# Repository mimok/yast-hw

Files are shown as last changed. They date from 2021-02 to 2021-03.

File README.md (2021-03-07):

# Yet Another Security Token v1.0
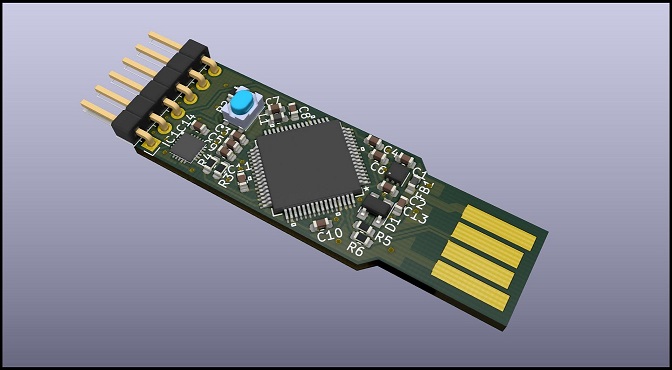
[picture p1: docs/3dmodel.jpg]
YAST token illustration v1.0


## Purpose of this token
This repository contains the hardware source files of the YAST security token.
This security token is intented to be used as a development platform for security applications.
It is built around a LPC55Sxx chip and a SE050 secure element both from NXP.
This token as the same form factor as the [OpenSK](https://github.com/google/OpenSK) token
from Google therefore its [case](https://www.thingiverse.com/thing:4132768) can be reused.

## Disclaimer
YAST is designed to be a development board and therefore should not be used as a daily security token.

## What is the added value of YAST?
On the market there is already a large amount of security tokens.
Most of them are based on proprietary designs while some others are open source.
On one hand, closed source tokens seem to be based on secure elements while on the other hand, as far as I know, open source tokens
are based on standard, not security certified, chips like STM32 chips.
This design choice seems to be mainly dictated by concerns about NDA which come with Secure Elements.

From my point of view this is a real problem. I agree some tokens based on secure elements are not exempt from vulnerabilities like the 
[Titan security key](https://www.zdnet.com/article/new-side-channel-attack-can-recover-encryption-keys-from-google-titan-security-keys/) from Google.
In fact, this token is based on a pretty old secure element A7005 from NXP and therefore things which were secure almost ten years ago are no more secure now.
However if a old secure element is now vulnerable (but more than 4 months of work were needed to discover and exploit the vulnerability), 
old non secure chips are **far more** vulnerable. For example, it is possible to [extract the firmware](https://blog.zapb.de/stm32f1-exceptional-failure/) 
from an STM32F1 chip using a pure software attack (ok this is not entirely true as an access to the SWD port is needed). 
This is this chip which is used in the Nitrokey Start key from Nitrokey. While using a secure element is not a "cure-all", 
using non-secure and non-certified chips for secure application is almost always a bad idea as you relies on a "untrusted" 
(not certified) chip exectuting an "untrusted" (not certified) code. 
Here openness is not really a huge advantage as there is very few people around the world which have the required 
skills needed to perform a valuable security assessment of a security token.

So how a security token can be built using a secure element and still be open source? 
[SE050 security chip](https://www.nxp.com/products/security-and-authentication/authentication/edgelock-se050-plug-trust-secure-element-family-enhanced-iot-security-with-maximum-flexibilit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) 
from NXP is a pre-programmed secure element embedding a really versatile security applet. 
All documentation is freely accessible on NXP's website (some documentation requires an account to be accessible) and therefore no NDA is required. 
The YAST key embeds both a LPC55Sxx chip and the SE050 SE. LPC55Sxx chip can be binded to its SE050 companion using its embedded PUF (Physical Unclonable Function). 
The resulting hardware comes with both the flexibility and the power of the LPC55 chip and the security of the SE050 secure element which has been certified at level EAL6+ (Hardware and OS) according to the Common Criterias.

## For which application the YAST token can be used?
YAST token is made of a LPC55Sxx MCU connected to a SE050 coprocessor which acts as a secure cryptographic library.
SE050 is designed to prevent both leakage of cryptographic keys and their usage by unauthorized users. In consequence, YAST token is suited for
applications which extensively use cryptographic primitives. However, others processing taking place on the LPC55 side do not benefit from SE050 high
security level. So before using YAST token for a given application, you should be sure that the following hypothesis are verified:
- LPC55Sxx does not implements any security functions and it is only used as an interface between SE050 chip and the host PC.
- Or, LPC55Sxx implements some security function but they can only be used if the user is properly authenticated by the SE050 **and** , 
if we consider the application threat model,the user is not willing to attack his own token.

Concretely, the YAST token can be used to implement application like OpenPGP card (demo application available), 
FIDO2 protocol (but YAST token does not have any led) or HSM-like applications.

SE050 has some functional limitations which can be circumvented:

- PIN object cannot be atomically updated. You have to first delete then create a new PIN object. 
If a power loss occurs between PIN deletion and creation then the secure element remains in an improper state which can be exploited by an attacker. 
Therefore my advise is to lock the secure element using the new PIN before the deletion of the old PIN and unlock the SE at the end of the process. 
In case of power loss during PIN update, the SE is locked at next reboot and the improper state of the SE cannot be exploited by an attacker which does not have the knowledge of the new PIN.
- PIN try counters of PIN objects cannot be read (while there are effectively decremented when a wrong PIN is entered) 
so you will have to manage these counters by yourself. This limitation is corrected in the new version of the SE050 which is not yet available.

At the moment, due to a shortage in LPC55S69 chips, YAST token is based on a LPC55S28 chip which does not implement TrustZone.
However these two chips are PIN compatible and token design does not need to be changed if one wants to update the chip.

## Building the YAST token yourself
You can easily build this token yourself. The token is designed using Kicad v5 and you can inspect or modify its design.
You will need a PCB with a thickness of at least 2.0mm (best 2.4mm). You can also use a small piece of tape to improve the thickness of your PCB.
You should dispense paste on the PCB using a stencil. I use unleaded low temperature Chip Quik SMDLTLFP paste (melting point at 138°C).
Placement is not so hard because CMS are not smaller than 0603. The regulator, the SE050 and the LPC55 are the hardest parts to place.
Soldering is an easy game if you use a hot plate and a hot-air rework station.

## Programming and debugging
A 6-pin header is available for programming and debugging purpose through LPC55 SWD port. 
A low cost [LPC Link-2](https://www.nxp.com/design/microcontrollers-developer-resources/lpc-microcontroller-utilities/lpc-link2:OM13054)
from NXP can be used as a debugging probe. You should update it with the [segger firmware](https://www.segger.com/products/debug-probes/j-link/models/other-j-links/lpc-link-2/) to obtain the best performances.
USB port can also be used to program the LPC55 chip through the on-chip bootloader:

1. First you will have to enable the USB0 interface in the bootloader configuration. To do so, you can load and execute the following [piece of code](docs/unlock_USB0_bootloader.c) trough SWD interface.
2. Once bootloader has been unlocked, press the button on the token and plug it on your computer. Bootloader should be automatically detected on WIN10.
3. Then use [blhost](https://www.nxp.com/design/software/development-software/mcuxpresso-software-and-tools-/mcuboot-mcu-bootloader-for-nxp-microcontrollers:MCUBOOT) tool from NXP to flash your firmware:
    1. Compile your program using your preferred IDE (e.g. MCUXpresso) and generate an HEX file.
    2. Load the new HEX file using the following commands:

```bash
blhost -u 0x1FC9,0x21 -- flash-image <path_to_hex_file> erase 0
blhost -u 0x1FC9,0x21 -- reset
```

## Plastic case for YAST token
This token as the same form factor as the [OpenSK](https://github.com/google/OpenSK) token
from Google therefore its [case](https://www.thingiverse.com/thing:4132768) can be reused.
The case can be built using a 3D Printer and PLA plastic.

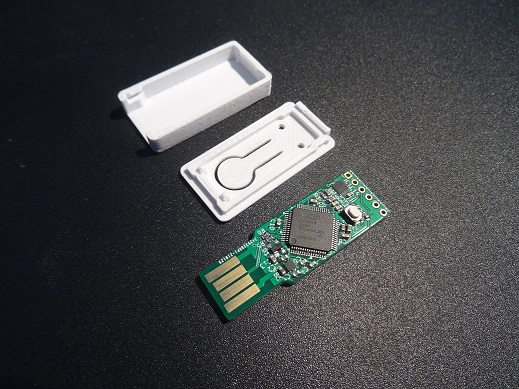
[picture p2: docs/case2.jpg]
Unmounted case


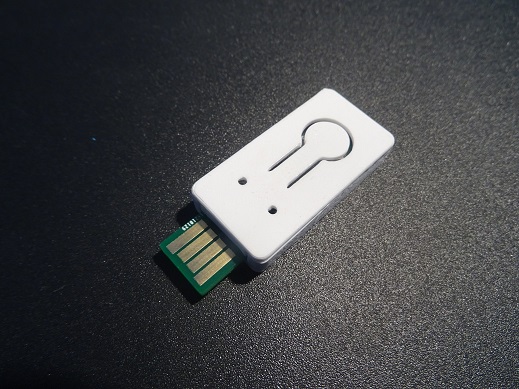
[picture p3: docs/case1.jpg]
Mounted case


## License
This work is licensed under CC BY-SA 4.0

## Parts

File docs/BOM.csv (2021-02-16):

Reference | Quantity | Value | Manufacturer_Name | Manufacturer_Part_Number
C1 C2 | 2 | 1uF | Taiyo Yuden | EMK107BJ105KA-T
C13 | 1 | 2.2uF | Taiyo Yuden | EMK107BJ225KA-T
C14 C11 C10 C6 C4 C5 C8 | 7 | 100nF | AVX | 0603YC104MAT4A
C3 | 1 | 47pF | Wurth Elektronik | 885012006021
C9 C7 | 2 | 10uF | Taiyo Yuden | EMK107BBJ106MA-T
D1 | 1 | PRTR5V0U2X | Nexperia | PRTR5V0U2X,215
FB1 | 1 | 221R | Laird Performance Materials | MI0603L221R-10
IC1 | 1 | SE050C1HQ1_Z01SCZ | Nexperia | SE050C1HQ1/Z01SCZ
L1 | 1 | 4.7uH | TDK | MLZ1608M4R7WT
R2 | 1 | 10k | Vishay | CRCW060310K0JNEBC
R3 R4 | 2 | 560R | Yageo | RC0603FR-07560RL
R5 R6 | 2 | 33R | Vishay | CRCW060333R0FKEAC
SW1 | 1 | PTS810 SJK 250 SMTR LFS | C&K Switches | PTS810SJK250SMTRLFS
U1 | 1 | LPC55S28JBD64 | NXP | LPC55S28JBD64
U2 | 1 | TLV75533PDRV | TI | TLV75533PDRV
 | 25

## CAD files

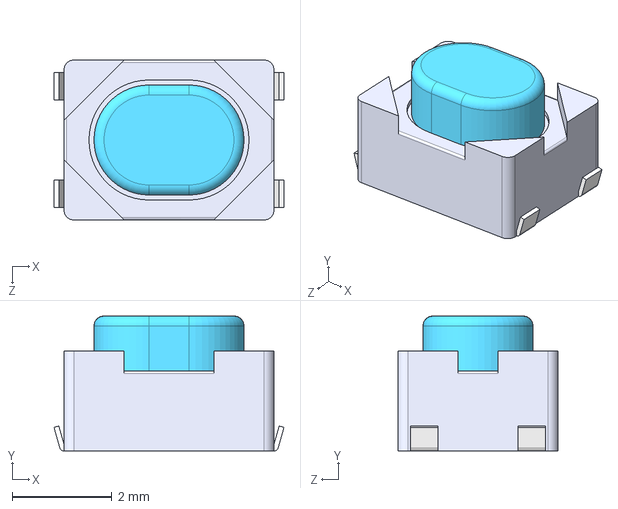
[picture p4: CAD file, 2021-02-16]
shapes3D/PTS810SJK250SMTRLFS--3DModel-STEP-56544.STEP
4.60 x 2.70 x 3.20 mm

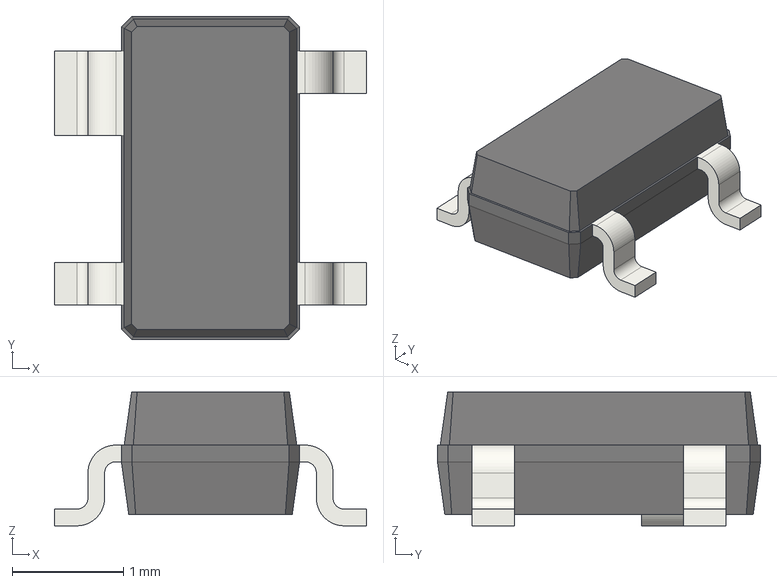
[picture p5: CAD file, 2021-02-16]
shapes3D/SOT-143.step
2.80 x 2.90 x 1.20 mm

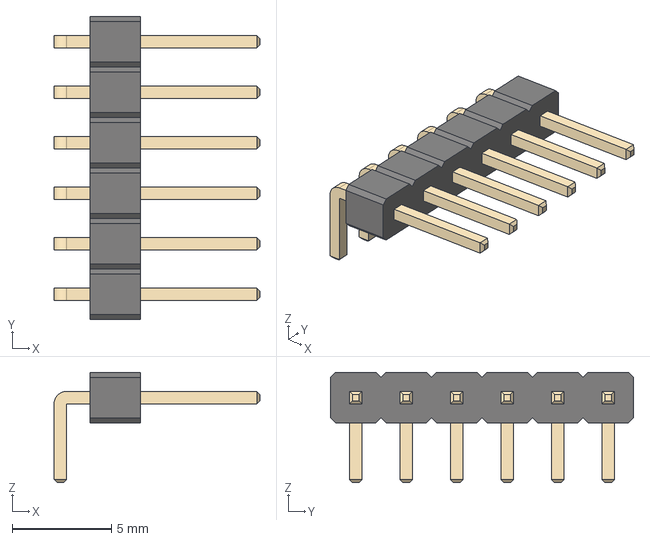
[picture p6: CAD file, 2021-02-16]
shapes3D/PinHeader_1x06_P2.54mm_Horizontal.step
10.4 x 15.2 x 5.54 mm

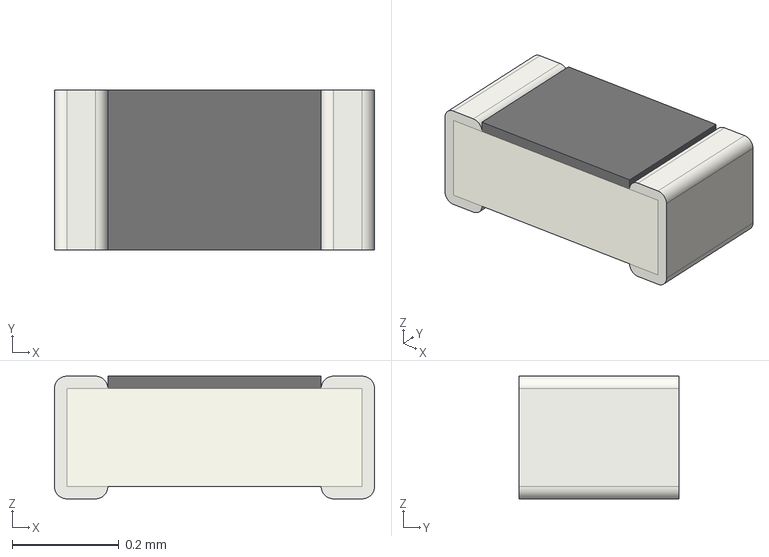
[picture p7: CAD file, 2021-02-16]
shapes3D/R_0201_0603Metric.step
0.6 x 0.3 x 0.23 mm

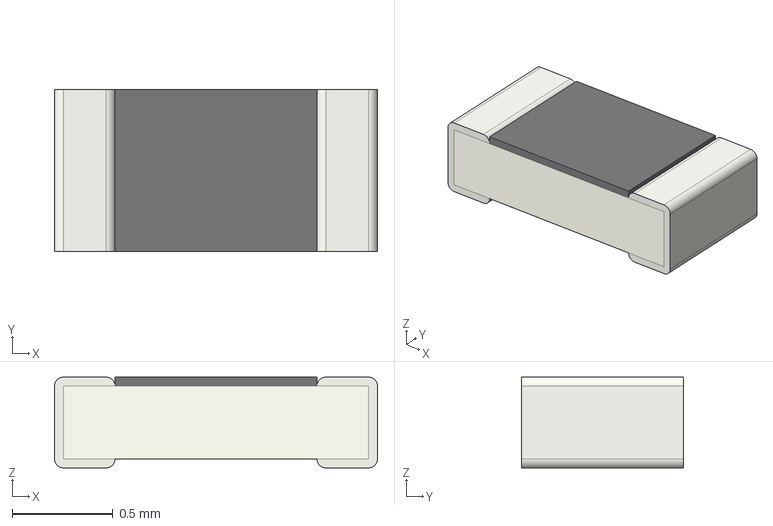
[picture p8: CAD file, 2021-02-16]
shapes3D/R_0603_1608Metric.step
1.60 x 0.8 x 0.45 mm

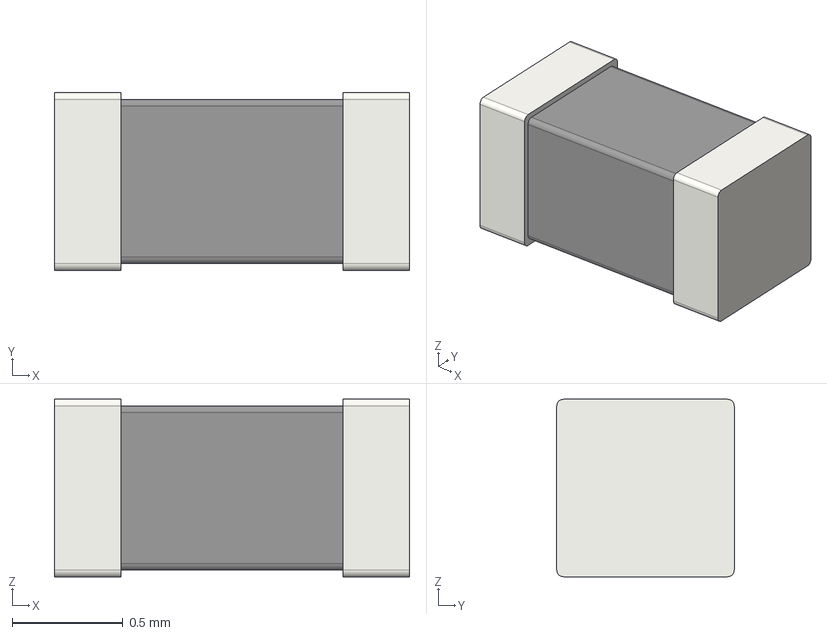
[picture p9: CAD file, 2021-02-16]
shapes3D/L_0603_1608Metric.step
1.60 x 0.8 x 0.8 mm

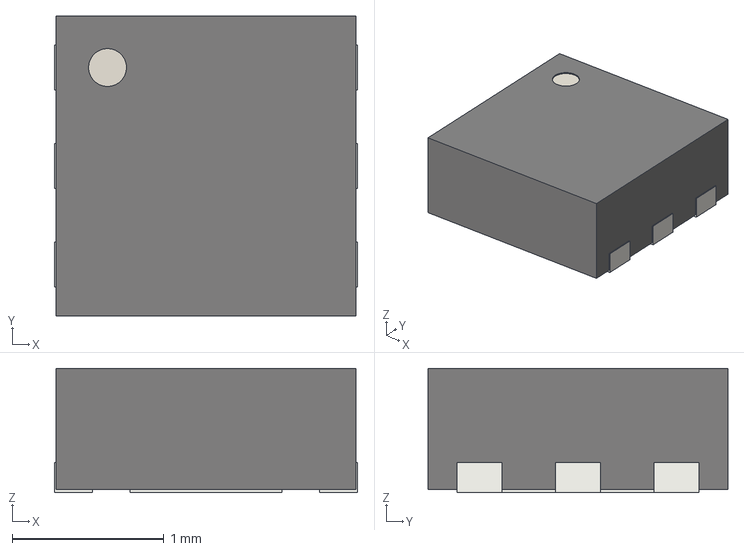
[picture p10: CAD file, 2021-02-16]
shapes3D/WSON-6-1EP_2x2mm_P0.65mm_EP1x1.6mm.step
2.00 x 1.98 x 0.82 mm

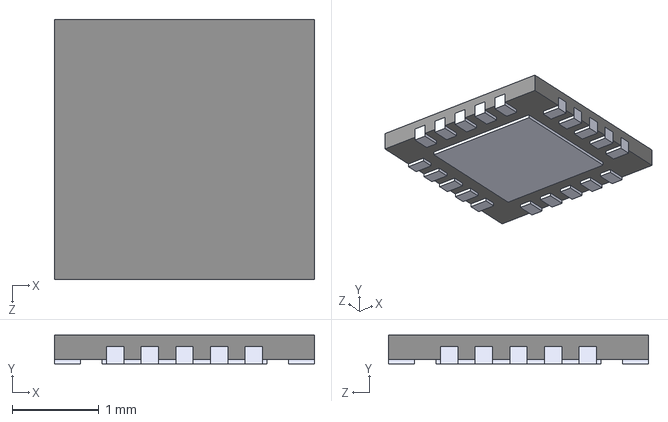
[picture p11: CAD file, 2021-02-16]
shapes3D/Z01SCZ.STEP
3.00 x 0.33 x 3.00 mm

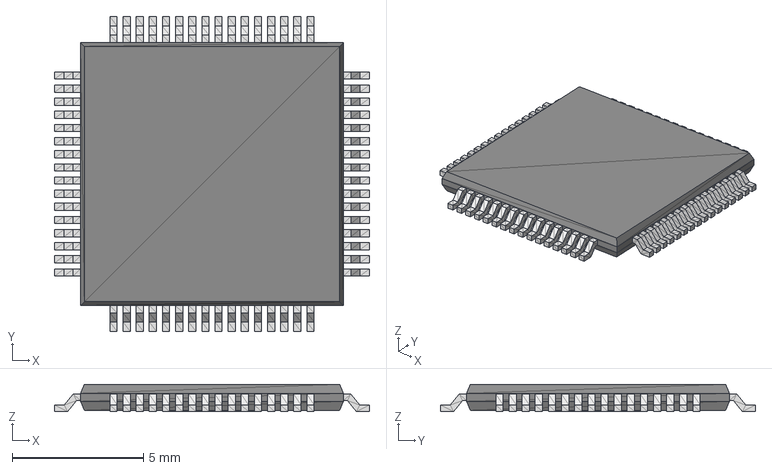
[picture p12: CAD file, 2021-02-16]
shapes3D/HTQFP64.stp
12.0 x 12.0 x 1.04 mm

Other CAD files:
shapes3D/C_0603_1608Metric.step
shapes3D/HTQFP64.stl

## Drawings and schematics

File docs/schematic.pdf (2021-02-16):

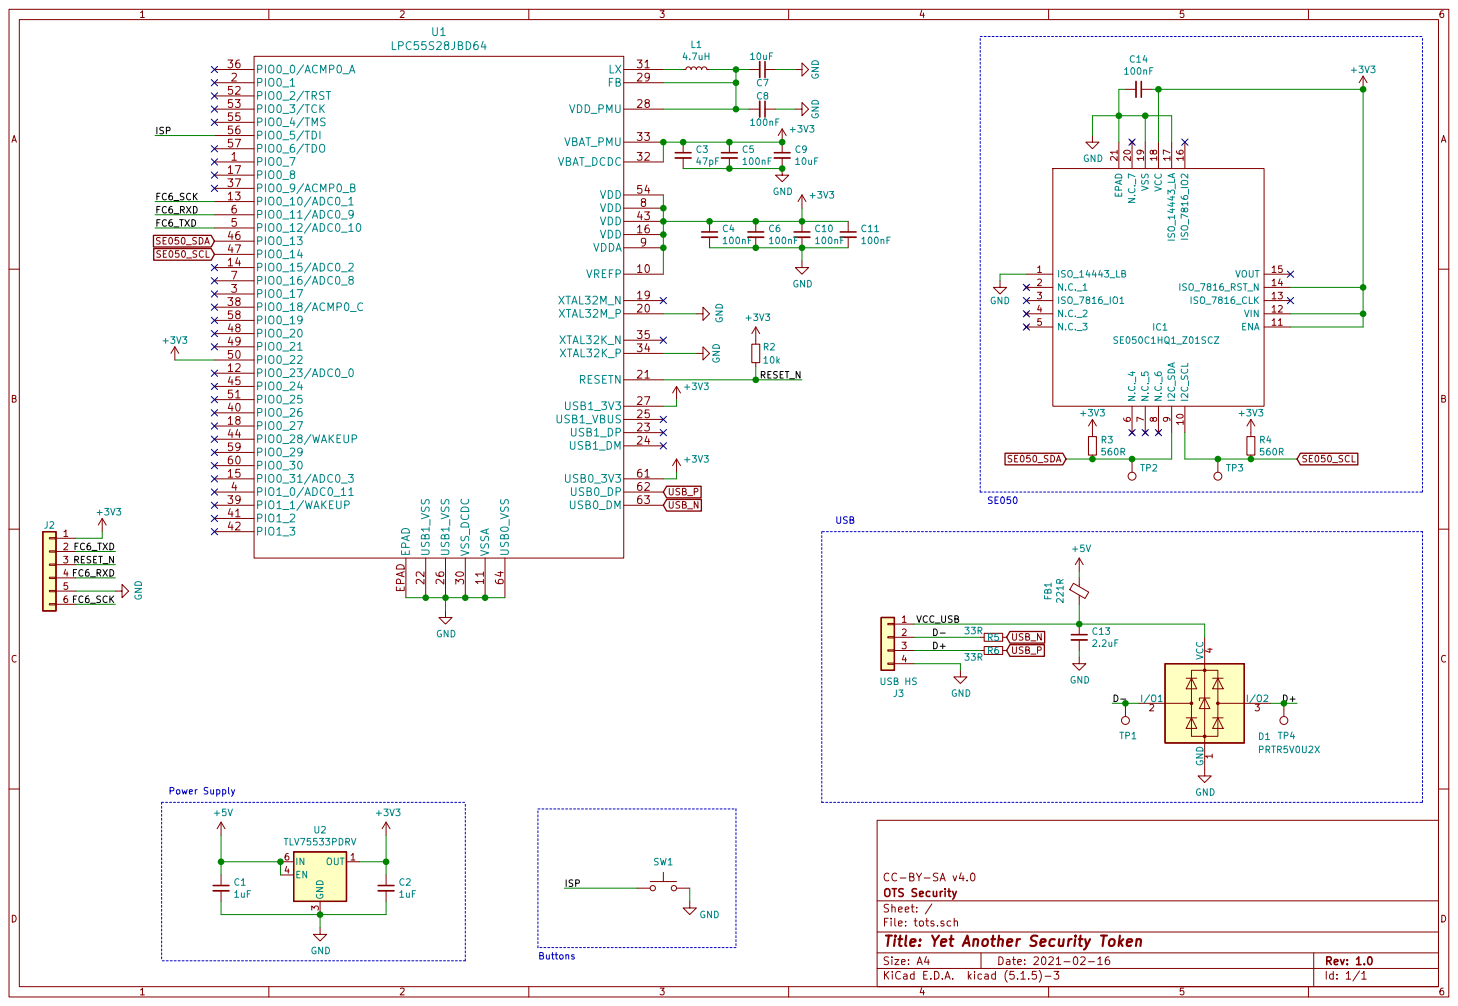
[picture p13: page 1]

SW1 ISP | GND

File: tots.sch Sheet: / OTS Security CC-BY-SA v4.0

Id: 1/1 Title: Yet Another Security Token

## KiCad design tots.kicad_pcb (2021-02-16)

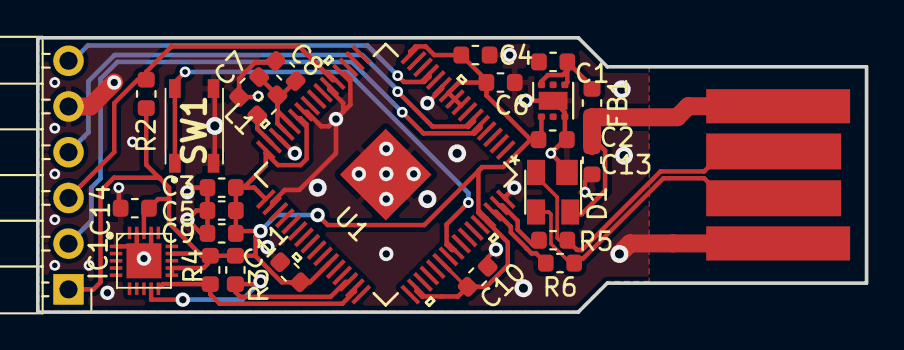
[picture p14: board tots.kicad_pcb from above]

Board: 2 copper layers, 46.0 x 15.2 mm, 27 parts (0 on the bottom side), 17 nets.

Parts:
C1, C2: 1uF; C_0603_1608Metric
C3: 47pF; C_0603_1608Metric
C4, C5, C6, C8, C10, C11, C14: 100nF; C_0603_1608Metric
C7, C9: 10uF; C_0603_1608Metric
C13: 2.2uF; C_0603_1608Metric
D1: PRTR5V0U2X; SOT-143
FB1: 221R; L_0603_1608Metric
IC1: SE050C1HQ1_Z01SCZ; QFN40P300X300X33-21N-D
J2: Conn_01x06; PinHeader_1x06_P2.54mm_Horizontal
J3: USB HS; usb-PCB
L1: 4.7uH; L_0603_1608Metric
R2: 10k; R_0603_1608Metric
R3, R4: 560R; R_0603_1608Metric
R5, R6: 33R; R_0603_1608Metric
SW1: PTS810 SJK 250 SMTR LFS; PTS810SJG250SMTRLFS
U1: LPC55S28JBD64
U2: TLV75533PDRV; WSON-6-1EP_2x2mm_P0.65mm_EP1x1.6mm

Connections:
+3V3: C2.1, C3.1, C4.1, C5.1, C6.1, C9.1, C10.1, C11.1, C14.1, IC1.11, IC1.12, IC1.14, IC1.18, J2.1, R2.1, R3.1, R4.1, U1.8, U1.9, U1.10, U1.16, U1.27, U1.32, U1.33, U1.43, U1.50, U1.54, U1.61, U2.1
+5V: C1.1, FB1.1, U2.4, U2.6
/D+: D1.3, J3.3, R6.2
/D-: D1.2, J3.2, R5.2
/FC6_RXD: J2.4, U1.6
/FC6_SCK: J2.6, U1.13
/FC6_TXD: J2.2, U1.5
/ISP: SW1.1, SW1.2, U1.56
/RESET_N: J2.3, R2.2, U1.21
/VCC_USB: C13.1, D1.4, FB1.2, J3.1
GND: C1.2, C2.2, C3.2, C4.2, C5.2, C6.2, C7.1, C8.1, C9.2, C10.2, C11.2, C13.2, C14.2, D1.1, IC1.1, IC1.17, IC1.19, IC1.21, J2.5, J3.4, SW1.3, SW1.4, U1.11, U1.20, U1.22, U1.26, U1.30, U1.34, U1.64, U1.EPAD, U2.3, U2.7
unnamed: C7.2, C8.2, L1.2, U1.28, U1.29
unnamed: L1.1, U1.31
SE050_SCL: IC1.10, R4.2, U1.47
SE050_SDA: IC1.9, R3.2, U1.46
USB_N: R5.1, U1.63
USB_P: R6.1, U1.62

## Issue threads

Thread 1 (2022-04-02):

SE050E

immesys, 2022-04-02:
Thanks so much for this project. I was about to design a PCB for this chip, but you've done all the work! I'm about to order some PCBs and build this with an SE050E, rather than the 050C called for in the BOM. Is there anything I should know not documented in the repo (lessons learned over the past 14 months), or any reason to believe the SE050E would not work?

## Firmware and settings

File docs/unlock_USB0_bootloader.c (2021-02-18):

/*
 * Copyright 2018 NXP
 * Copyright 2021 Michael Grand
 * All rights reserved.
 *
 * SPDX-License-Identifier: BSD-3-Clause
 */

#include "fsl_debug_console.h"
#include "pin_mux.h"
#include "board.h"
#include "fsl_iap.h"
#include "fsl_iap_ffr.h"
#include "fsl_common.h"
#include "fsl_power.h"
////////////////////////////////////////////////////////////////////////////////
// Definitions
////////////////////////////////////////////////////////////////////////////////

////////////////////////////////////////////////////////////////////////////////
// Prototypes
////////////////////////////////////////////////////////////////////////////////
static void verify_status(status_t status);
static void error_trap();
////////////////////////////////////////////////////////////////////////////////
// Variables
////////////////////////////////////////////////////////////////////////////////
#define BUFFER_LEN 512 / 4
static uint32_t s_buffer_rbc[BUFFER_LEN];
////////////////////////////////////////////////////////////////////////////////
// Code
////////////////////////////////////////////////////////////////////////////////
int main() {
	flash_config_t flashInstance;
	static uint32_t status;
	uint32_t destAdrss; /* Address of the target location */
	uint32_t failedAddress, failedData;
	uint32_t pflashBlockBase = 0;
	uint32_t pflashTotalSize = 0;
	uint32_t pflashSectorSize = 0;
	uint32_t PflashPageSize = 0;
	const uint32_t s_buffer[BUFFER_LEN] = { 1, 2, 3, 4 };
	uint8_t data[512];
	cmpa_cfg_info_t cmpa = { 0x00 };
	/* Init board hardware. */
	/* set BOD VBAT level to 1.65V */
	POWER_SetBodVbatLevel(kPOWER_BodVbatLevel1650mv, kPOWER_BodHystLevel50mv,
	false);
	/* attach 12 MHz clock to FLEXCOMM0 (debug console) */
	CLOCK_AttachClk(BOARD_DEBUG_UART_CLK_ATTACH);
	/* enable clock for GPIO*/
	CLOCK_EnableClock(kCLOCK_Gpio0);
	CLOCK_EnableClock(kCLOCK_Gpio1);

	BOARD_InitPins();
	BOARD_BootClockFROHF96M();
	BOARD_InitDebugConsole();

	PRINTF("\r\nUSB0 interface enabling for LPC55Sxx ISP\r\n\r\n");

	PRINTF("Initializing flash driver...\r\n");
	status = FLASH_Init(&flashInstance);
	verify_status(status);
	if(status != kStatus_Success) {
		error_trap();
	}

	PRINTF("Initializing PFR flash driver...\r\n");
	status = FFR_Init(&flashInstance);
	verify_status(status);
	if(status != kStatus_Success) {
		error_trap();
	}

	PRINTF("Reading CMPA\r\n");
	status = FFR_GetCustomerData(&flashInstance, (uint8_t*) &cmpa, 0, sizeof(cmpa));
	verify_status(status);
	if (status != kStatus_FLASH_Success) {
		error_trap();
	}

	PRINTF("Enabling USB0 interface\r\n");
	if ((cmpa.bootCfg & (1 << 9)) == 0) {
		cmpa.bootCfg |= 1 << 9;
		status = FFR_CustFactoryPageWrite(&flashInstance, (uint8_t*) &cmpa, false);
		verify_status(status);
		if (status != kStatus_FLASH_Success) {
			error_trap();
		}
		PRINTF("Reset the board...\r\n");
	} else {
		PRINTF("Nothing to do!\r\n");
		PRINTF("USB0 interface is already enabled\r\n");
	}

	while (1) {
	}
}

void verify_status(status_t status) {
	char *tipString = "Unknown status";
	switch (status) {
	case kStatus_Success:
		tipString = "Done!";
		break;
	case kStatus_InvalidArgument:
		tipString = "Invalid argument.";
		break;
	case kStatus_FLASH_AlignmentError:
		tipString = "Alignment Error.";
		break;
	case kStatus_FLASH_AccessError:
		tipString = "Flash Access Error.";
		break;
	case kStatus_FLASH_CommandNotSupported:
		tipString = "This API is not supported in current target.";
		break;
	default:
		break;
	}
	PRINTF("%s\r\n\r\n", tipString);
}

/*
 * @brief Gets called when an error occurs.
 */
void error_trap(void) {
	PRINTF("\r\n\r\n\r\n\t---- HALTED DUE TO FLASH ERROR! ----");
	while (1) {
	}
}

////////////////////////////////////////////////////////////////////////////////
// EOF
////////////////////////////////////////////////////////////////////////////////

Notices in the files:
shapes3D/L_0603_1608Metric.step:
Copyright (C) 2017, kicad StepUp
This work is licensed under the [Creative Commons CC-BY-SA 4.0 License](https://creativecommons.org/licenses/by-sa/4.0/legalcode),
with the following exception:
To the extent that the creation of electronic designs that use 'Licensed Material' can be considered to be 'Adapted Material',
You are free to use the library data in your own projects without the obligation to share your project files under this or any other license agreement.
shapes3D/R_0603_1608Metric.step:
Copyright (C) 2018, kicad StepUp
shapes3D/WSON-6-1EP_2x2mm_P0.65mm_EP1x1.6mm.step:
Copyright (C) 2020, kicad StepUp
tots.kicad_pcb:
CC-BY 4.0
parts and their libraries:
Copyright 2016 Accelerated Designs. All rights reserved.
